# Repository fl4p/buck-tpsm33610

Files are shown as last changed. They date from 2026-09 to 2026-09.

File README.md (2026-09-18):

# buck-tpsm33610

A 3–36 V to 3.3 V, 1 A break-out board for the TI **TPSM33610S3QRDNRQ1** — a
synchronous buck *module* with the controller, both FETs, the inductor and the
bootstrap capacitor inside one 3.5 × 4.5 × 2.1 mm QFN-FCMOD package.

**9.01 × 12.525 mm**, 2 layers, one 2.54 mm header row: VIN, GND, VOUT.

> **Status: unbuilt.** This board has never been fabricated, assembled or
> powered. No gerbers have been generated. Every number below is either a
> datasheet value or a computed estimate — none of it is a bench measurement.
> Treat it as a design under review, not a validated product.

## What is generated

Everything. The KiCad symbol, footprints, schematic and PCB are all outputs of
the Python in this repo; the `.kicad_sch` and `.kicad_pcb` are build artefacts
and hand edits in the GUI are overwritten on the next run.

```
variants.py           geometry constants -- the single source of truth
project_settings.py   owns .kicad_pro design rules; apply() / verify()
gen_sym.py         -> lib/buck-tpsm33610.kicad_sym
gen_fp.py          -> lib/buck-tpsm33610.pretty/*.kicad_mod
gen_sch.py         -> buck-tpsm33610.kicad_sch
gen_pcb.py         -> buck-tpsm33610.kicad_pcb   (placement, routing, pours, fill)
check_netlist.py      capture-completion gate
```

Regenerate, in order. `gen_pcb.py` needs KiCad's bundled interpreter, the only
one that can `import pcbnew`:

```sh
KI=/Applications/KiCad/KiCad.app/Contents
KIPY=$KI/Frameworks/Python.framework/Versions/Current/bin/python3
CLI=$KI/MacOS/kicad-cli

python3 gen_sym.py && python3 gen_fp.py && python3 gen_sch.py
$CLI sch erc --severity-all --exit-code-violations -o erc.rpt buck-tpsm33610.kicad_sch
$CLI sch export netlist -o buck-tpsm33610.net buck-tpsm33610.kicad_sch
$KIPY gen_pcb.py
$CLI pcb drc --severity-all --schematic-parity --exit-code-violations \
     -o drc.rpt buck-tpsm33610.kicad_pcb
```

Built and verified against KiCad 10.0.5.

Two flags matter more than they look. `--exit-code-violations` is not
decoration: without it `kicad-cli` writes the violations to the report and still
exits 0. And DRC is deliberately run **without** `--refill-zones` — re-pouring
from the project at check time grades a board that is not the one in the file,
and that is exactly how an isolated pad hid here once.

## Design

| | |
|---|---|
| Input | 3–36 V (40 V abs max), no reverse-polarity or transient protection |
| Output | 3.3 V fixed, 1 A, ±1 % |
| Switching | 2.2 MHz, auto/PFM by default (see DRSS note below) |
| Layers | 2 × 35 µm (1 oz), ENIG, 1.6 mm FR4 |
| Drawn to | 150 µm track / 150 µm clearance |
| I/O | one 1×3 header, 2.54 mm: VIN, GND, VOUT |
| Control | EN, PGOOD, MODE on 1.0 mm solder pads; JP1 selects FPWM |

Pin rules from TI **SNVSCS7E** that shape the whole layout: SW (5, 6) carries no
copper beyond its lands; BOOT (7) is a no-connect because the 100 nF is internal;
MODE/SYNC (11) has a **5.5 V abs max** and must never reach VIN; PGOOD (1) tops
out at 20 V, so its pull-up goes to VOUT. `gen_sch.py` asserts these as an
abs-max-per-pin gate at generation time, so a net that could over-volt a pin
fails the build rather than the board.

The datasheet states the 100 nF bootstrap cap is internal (p.5, pin 7) and
requires external bypass at VIN (p.5, pin 3). It does not say whether any
internal VIN bypass exists; assume none and bypass externally.

### Two layers

TI's datasheet asks for four. The cost is quantified rather than waived: on a
1.6 mm two-layer board the image plane sits 1.6 mm below F.Cu instead of ~0.2 mm,
so a top-side switching run encloses roughly 8× the area. What makes it
defensible is that the highest-di/dt loop is kept small locally and the back side
is one unbroken ground pour.

### Verification gates

The generators are gates, not reports — each fails the build:

- **Fill runs in a clean subprocess.** `CreateEmptyBoard()` loads KiCad's default
  project into the interpreter, and a later `LoadBoard()` in the same process
  keeps those defaults, so an in-process pour uses the wrong clearances. This
  cost a silently isolated pad once.
- **Connectivity after fill** — every pad must reach every other pad on its net,
  or the build fails.
- **Courtyard overlap by polygon intersection**, not inflated bounding boxes.
- **Abs-max per U1 pin** from the datasheet table.
- **BOM line consistency** — parts sharing an MPN must agree on value and footprint.
- **MODE never floats** in any jumper state.

## Known and open

- **Thermal is an estimate, not a measurement, and the estimate is unsourced.**
  ~120 °C/W at the 35 µm this board actually specifies, against TI's 54.1 °C/W
  JESD 51-7 four-layer figure and 22 °C/W for their EVM. No derivation for that
  number exists in this repo — treat it as an order-of-magnitude expectation, not
  a bounded estimate. That predicts full 1 A to roughly 80 °C ambient at
  24 V and ~64 °C at 36 V. Unverified. ΨJB is 16.3 °C/W, so the acceptance test
  is to probe board temperature beside the GND land and compute
  `Tj = Tboard + 16.3 × Pd`.
- **Input loop inductance: 3.67 nH of board copper** (C1‖C2), extracted with
  FastHenry at 0.25 mm mesh pitch, ±1 % over a 2.5× pitch range. This is **board
  copper only and a lower bound** — the module's pad-to-die path is not published
  and is deliberately not estimated. Not cross-checked against hardware. **The
  extraction tool is not in this repo** and neither is its output, so nothing here
  substantiates that figure; it is reproduced from an external run.
- **The VIN neck is 0.245 mm and is marginal at the specified copper weight.**
  At 35 µm, IPC-2221 gives **0.86 A at 10 K rise and 1.17 A at 20 K**. Worst-case
  input current is ~1.0–1.1 A, which occurs at the low end of the *regulating*
  input range (around 3.5–4 V, where duty is highest); below that the part is in
  dropout and no longer making 3.3 V. So the neck sits **above its 10 K rating and
  inside its 20 K rating** — it works, at a higher local rise than is comfortable.
  At 70 µm the same neck gives 1.43 A / 1.93 A and is unambiguously fine. TI asks
  for 2 oz outer layers (SNVSCS7E p.35 item 6); this board is drawn at 1 oz.
- **Resistance of the declared power paths** at 35 µm, 0.1 mm solver grid:
  `/VIN C1.1↔U1.3` 9.27 mΩ, `/VIN J1.1↔U1.3` 11.04, `GND J1.2↔U1.10` 3.23,
  `GND C2.2↔U1.10` 2.36, `/VOUT J1.3↔U1.4` 1.84, `/VOUT U1.4↔C4.1` 0.96.
- **Spread spectrum is mostly OFF in the shipped default.** Table 7-2 calls the
  MODE-low state "auto mode with spread spectrum", but §7.3.8 p.18 overrides it:
  DRSS is disabled whenever the clock is not free-running — including when the
  clock slows under light load in auto mode, and in dropout. Bridge JP1 for FPWM
  if you want DRSS active at light load.
- **Two accepted DRC warnings**: the C1–C4 courtyard overlap (side-by-side pair
  whose cheapest escape is X, not Y) and an R3/R6 silkscreen clearance. Zero
  errors, zero unconnected pads. The generators cite a `DESIGN.md` for the
  per-pair disposition of those warnings; **that file does not exist**, so the
  waiver is currently undocumented.
- **No input protection at all** — no TVS, no reverse-polarity FET, not even a
  DNP land. EN is hard-tied to VIN. Nothing here survives a hot-unplug inductive
  kick on a long 36 V lead. Bench use from a stiff supply only.
- `make_fab.py` is not written, so there are no gerbers and no assembly data.

## Datasheet

TI **SNVSCS7E**, "TPSM336xx-Q1". Not redistributed here —
`datasheets/PROVENANCE.md` carries the source URL and the SHA-256 of the exact
revision every page citation in this repo refers to.

## History

Developed inside a private monorepo; this repository starts from a squashed
snapshot, so the per-change history is not carried over.

## Licence

Not yet chosen, so no licence is granted — all rights reserved for now. If you
want to use any of this, open an issue and ask.

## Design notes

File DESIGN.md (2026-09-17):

# buck-tpsm33610 — design record

This file exists because four generators defer to it: `gen_sch.py` for design
intent and the capture record, `gen_pcb.py` and `project_settings.py` for the
courtyard-warning disposition, and `gen_fp.py` for the copper-weight claim. It
was missing until 2026-09-17 — an independent review found that the DRC waivers
were made **by reference to a document that did not exist**. Every disposition
below is either evidence or is labelled as a preference.

Status of the board: **unbuilt**. Nothing here is a bench measurement.

---

## 1. Intent

TI's Table 8-3 fixed-output application — CIN bulk + 100 nF HF, CVCC, one COUT,
FB tied to VOUT — plus exactly three additions:

1. **R1, a 0 Ω RFBT that doubles as the fixed/adjustable selector.** §7.3.2.1
   p.12: the part *"determines whether fixed output voltage or adjustable output
   voltage is required by sensing the resistance of the feedback path during
   start-up."* 0 Ω fitted = fixed. Retune R1 and fit R2 to go adjustable.
2. **R4/R5, an EN strap that can become a UVLO divider.** R4 = 0 Ω VIN→EN as
   built.
3. **R6 + JP1, the MODE strap.** R6 100 k to GND is auto/PFM. Bridge JP1 for
   FPWM via VCC.

Everything else is either the datasheet's required external or a DNP land.

## 2. Capture record — as-captured netlist

Exported from `buck-tpsm33610.kicad_sch`, this is the artefact `--schematic-parity`
checks the PCB against:

```
/EN      R4.2 R5.1 TP1.1 U1.2
/FB      C6.2 R1.2 R2.1 U1.9
/MODE    JP1.2 R6.1 TP3.1 U1.11
/PGOOD   R3.2 TP2.1 U1.1
/SW      U1.5 U1.6
/VCC     C3.1 JP1.1 R3.1 U1.8
/VIN     C1.1 C2.1 J1.1 R4.1 U1.3
/VOUT    C4.1 C6.1 J1.3 R1.1 U1.4
GND      C1.2 C2.2 C3.2 C4.2 J1.2 R2.2 R5.2 R6.2 U1.10
unconnected-(U1-BOOT-Pad7) U1.7
```

`/SW` is a legitimate two-node net — pins 5 and 6 are the same internal node, and
a minimum-length inter-land stub satisfies ERC without inventing SW copper.
BOOT is explicitly no-connected; its capacitor is internal.

### Deviations from the original plan, and why

| plan | as built | why |
|---|---|---|
| J1 + J2, two 1×4 rows on 0.400 in, breadboard straddle | **one 1×3 header**, VIN GND VOUT | the board shrank to 9.01 mm wide, which cannot span 10.16 mm rows. The straddle was given up when the board was made small. |
| C7, second 22 µF COUT (DNP) | not placed | no room after the shrink |
| R7, MODE pull-up (DNP) | replaced by **JP1** | a solder jumper selects FPWM without a second fit option, and removes the R6/R7 mutual-exclusion hazard entirely |
| TP1–TP5 | TP1–TP3 (EN, PGOOD, MODE) | VOUT_SENSE and GND test pads dropped for space |
| 200 µm track / 200 µm clearance | **150/150** | see §5 |
| 70 µm copper | **35 µm** | see §5 |

## 3. DRC dispositions

DRC is run **without** `--refill-zones` — re-pouring from the project at check
time grades a board that is not the one in the file, and gerbers come from the
file. Current result: **0 errors, 0 unconnected pads, 2 warnings**, both below.

### `courtyards_overlap` — C1 / C4 — ACCEPTED

`project_settings.py` demotes this rule to *warning* rather than `ignore`, so it
still appears in every report and cannot pass unnoticed.

C1 (CIN bulk, 1206) and C4 (COUT, 1206) sit side by side in the southern power
row. Their courtyards are each the part's real body plus the standard IPC 0.25 mm,
and they overlap in X. **The copper does not.** The measured pad-to-pad copper gap
between the two parts clears `clearance_mm`, and `kicad_copper_collisions.py`
reports 0 collisions on the built board.

Why it is not fixed rather than waived: two overlapping courtyards share a Y range
by definition, so no cut line separates them — growing the board cannot reach this
pair, and their cheapest escape is X, which is the axis already at its limit.
Shrinking a courtyard to silence the warning would be a mute button: it would
change the reported number without changing the geometry.

**Accepted risk:** courtyard is a placement/assembly convention, not a fab rule.
Two 1206s at this spacing are within reflow practice. If this board is ever
hand-reworked with hot air, C1 and C4 will heat together.

### `silk_overlap` — R3 / R6 — ACCEPTED

0.070 mm between silkscreen segments against a 0.100 mm rule. R3 and R6 are two
of the five west-face rows, moved 0.25 mm south on 2026-09-16 to clear a
*courtyard* overlap; their reference designator outlines now touch.

This is ink on ink, not copper, and it is silkscreen-to-silkscreen rather than
silk-to-pad — no pad is obscured. The cost of fixing it is re-opening the west
cluster spacing that was just tightened to fix a real courtyard overlap.

**Accepted risk:** cosmetic. Two designators may bleed together on the printed
board.

## 4. MODE / JP1 — a hazard that is not a DRC finding

**Bridging JP1 while also driving TP3 shorts an external driver to VCC.**

JP1 open: MODE is held at GND through R6 100 k — auto/PFM. A clock or logic level
on TP3 overrides it, which is why R6 is 100 k and not 0 Ω.
JP1 bridged: MODE is tied to VCC — FPWM. **TP3 must then be left alone.** Driving
TP3 low against a bridged JP1 puts the external driver across the internal LDO.

This is stated in JP1's `Spec` field in the schematic as well as here.

MODE's absolute maximum is **5.5 V** (SNVSCS7E p.6) and VCC is 3.1–3.5 V, so the
bridged state is legal. MODE must never see VIN. `check_net_ceilings()` proves
that from the netlist rather than from a comment.

## 5. Process — 35 µm ENIG, and why the copper weight is not free

Confirmed by Fab 2026-09-16: **35 µm (1 oz) ENIG**.

TI asks for 2 oz outer layers and no less than 1 oz (p.35 item 6). This board is
at that floor, and the reason is the land, not the thermals:

- The RDN0011B land has a **0.100 mm minimum copper gap** (pins 1–11 and 8–9),
  which is finer than every published Aisler 2-layer rule. It is a deliberate,
  scoped rule break — decided 2026-09-13, Fab: *"the aisler rules are
  conservative, breaking the rules has always worked so far, no bad boards."*
- At **35 µm** that gap is 1.25× under the 125 µm ENIG rule, with an etch aspect
  ratio around 0.35:1 — the rule is margin, not physics.
- At **70 µm** it is 1.75× under *and* about 0.7:1 in aspect ratio, which is a
  physical limit. This is the one place on the board where the rule should not be
  broken.

Independently, the board is drawn to **150/150 µm** outside the land (35 copper
tracks sit on that floor). That clears Aisler's 125/125 ENIG rule but **not**
35 µm HASL's 200 µm track rule. So the process is pinned: **ENIG, 35 µm**, and
the copper weight is not a choice deferred to checkout.

### What 35 µm costs

- **Thermal.** The 70 µm option was worth roughly **10 °C of ambient headroom**.
  That figure and the ~105 → ~120 °C/W θJA behind it are **estimates with no
  derivation in this repo** — an order-of-magnitude expectation, not a bounded
  result. TI publishes 54.1 °C/W (JESD 51-7, four layers, 76.2 × 114.3 mm) and
  22 °C/W (four-layer EVM); this board is two layers and ~113 mm².
  **Acceptance test:** ΨJB is 16.3 °C/W (p.7), so probe board temperature beside
  the GND land and compute `Tj = Tboard + 16.3 × Pd`. Until that is done the
  thermal claim stays an estimate.
- **The VIN neck.** 0.245 mm at 35 µm gives IPC-2221 **0.86 A at 10 K rise,
  1.17 A at 20 K**. Worst-case input current is ~1.0–1.1 A, at the low end of the
  *regulating* input range (~3.5–4 V, where duty is highest); below that the part
  is in dropout and is not making 3.3 V. So the neck runs **above its 10 K rating
  and inside its 20 K rating**. Accepted: it works, warmer than is comfortable.

### Measured path resistances

35 µm, 0.1 mm solver grid, `copper_guards.py resistance`:

| path | mΩ | budget |
|---|---|---|
| /VIN C1.1↔U1.3 | 9.27 | 5 — see below |
| /VIN J1.1↔U1.3 | 11.04 | 25 |
| GND J1.2↔U1.10 | 3.23 | 10 |
| GND C2.2↔U1.10 | 2.36 | 5 |
| /VOUT J1.3↔U1.4 | 1.84 | 10 |
| /VOUT U1.4↔C4.1 | 0.96 | 3 |

**The 5 mΩ on `/VIN C1.1↔U1.3` is not a derived limit.** It was written into the
plan without a failure mode behind it, and it is recorded here as a preference so
that nobody — including a future me — cites it as a spec. The same applies to the
plan's `L_in(HF) ≤ 3 nH`. The input-loop criterion that *is* derived is the
**8 nH total**, from overshoot against the 40 V abs max (p.6): at ~0.33 A/ns,
8 nH gives 2.6 V and 36 + 2.6 = 38.6 V. FastHenry measures **3.67 nH of board
copper** for C1‖C2 — board copper only and a lower bound, since the module's
pad-to-die path is not published.

Note the solver's default `--grid 0.2` makes the GND solve **exactly singular**
(nan) on this board; the guard fails closed on it. Use `--grid 0.1`.

## 6. Known gaps

- **No gerbers.** `make_fab.py` is not written.
- **No staleness gate** between `gen_sch.py` → `.net` → `gen_pcb.py`. Nothing
  checks that the netlist was exported from the current schematic; run the chain
  in order. This bit during the 2026-09-17 session — a `gen_pcb.py` run consumed
  a netlist from the previous day.
- **`gen_fp.py` does not prune** stale `.kicad_mod` files. Four are generated and
  four are present, so nothing is stale today, but a footprint rename leaves the
  old file behind and the board can silently keep using it.
- **Two claims unverified** by the 2026-09-17 review: exact pad X/Y against the
  p.47 land drawing, and the measured `/SW` copper area.

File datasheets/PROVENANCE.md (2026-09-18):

# Datasheet provenance

Where each PDF in this directory came from, so a claim sourced from one can be
re-checked without guessing which document or revision was read.

| file | part | document | retrieved | source URL |
|---|---|---|---|---|
| `TI-TPSM336xx-Q1-SNVSCS7E-revE.pdf` | TI **TPSM33610S3QRDNRQ1** (U1) | **SNVSCS7E**, APRIL 2025 – REVISED SEPTEMBER 2026 (Rev. E) | 2026-09-13 | `https://www.ti.com/lit/ds/symlink/tpsm33610-q1.pdf` |

SHA-256:

```
59703a765616bffb3e0278fa0100bafd4b9f95aa9751f244311d5f2f2782d572  TI-TPSM336xx-Q1-SNVSCS7E-revE.pdf
```

Hashed **after** the copy into this directory, not at download.

**The PDF itself is not stored in this repository.** TI's document is not
redistributed here; fetch it from the source URL above and check it against the
SHA-256 before reading a number out of it. `datasheets/*.pdf` is gitignored.

## Fetch record

Rung 1 of the access ladder (plain `curl -L` with a desktop Chrome UA) returned
the document on the second URL tried. Recorded because the first URL is the one
an obvious guess produces and it is wrong:

| URL | result |
|---|---|
| `https://www.ti.com/lit/ds/symlink/tpsm33610.pdf` | **HTTP 404**, 3298 bytes of HTML — TI's "Error 404 not found" page, saved under a `.pdf` name. Not a datasheet. |
| `https://www.ti.com/lit/ds/symlink/tpsm33610-q1.pdf` | HTTP 200, 3 231 249 bytes, `%PDF-1.6`, 49 pages. **This file.** |
| `https://www.ti.com/lit/gpn/tpsm33610-q1` | HTTP 200, byte-identical to the above |

No WAF, no interstitial, no CAPTCHA. Judged by content: `pdfinfo` reports
`Keywords: SNVSCS7E`, `Author: Texas Instruments, Incorporated [SNVSCS7,E?]`,
`Title: TPSM336xx-Q1 Automotive, 3V to 36V Input, 1V to 7V Output, 0.6A, 1A, and
2A Synchronous Buck Converter Power Modules in a HotRod™ QFN Package With
Mitigated Interference and Noise Technology (MINT) datasheet (Rev. E)`.

## Why the family document, and what it costs

There is no `TPSM33610S3QRDNRQ1`-only datasheet. SNVSCS7E covers three current
ratings — TPSM33606-Q1 (0.6 A), **TPSM33610-Q1 (1 A, ours)** and TPSM33620-Q1
(2 A) — in two fixed-output trims (3.3 V `S3`, 5 V `S5`) plus an adjustable part.
**Most of the application tables in Section 8 are written against the 2 A part.**
Anything read from this document must therefore name the device column, not just
the page. In particular:

- **Table 8-1 and Table 8-2 (p. 26) are `TPSM33620-Q1`.** They call for
  2 × 22 µF of COUT. They are *not* the component table for this board.
- **Table 8-3 (p. 26) is the fixed-output `TPSM33610/06-Q1` table** — the one that
  applies here: CIN 4.7 µF + 100 nF, CVCC 1 µF, **COUT 1 × 22 µF**, RFBT short,
  RFBB and CFF do-not-populate.
- The **Thermal Information table (p. 7) is shared across all three dies**, and the
  RθJA figure printed there is measured on `TPSM33625EVM` (22 °C/W) or a 4-layer
  JESD 51-7 board (54.1 °C/W). Its own footnote says the JESD value "can not be
  used for design purposes."
- The **current-limit rows in the Electrical Characteristics (p. 7–8) are
  per-device.** Ours is `IL_HS` 1.7/2.0/2.3 A, `IL_LS` 0.85/1.1/1.4 A — *not* the
  3.4/4/4.6 A row, which is the 2 A part.

## Page map used by this project

Cite these page numbers, not section numbers alone; they are PDF pages of this
exact file (49 pages total).

| topic | page |
|---|---|
| Device Comparison Table — `TPSM33610S3QRDNRQ1` = "3.3 V fixed / adjustable", spread spectrum **yes** | 4 |
| Figure 5-1 pinout, **TOP VIEW**, + Pin Functions table | 5 |
| Absolute Maximum Ratings — VIN 40 V, **MODE/SYNC 5.5 V**, EN 40 V, PG 20 V, VOUT 16 V, FB 16 V | 6 |
| Thermal Information (RθJA 22 / 54.1, ΨJB 16.3) + Electrical Characteristics | 7–8 |
| §7.3.2 Output Voltage Selection; Eq. 1–3; Table 7-1 divider values | 12–13 |
| §7.3.3 Enable, start-up, shutdown | 14–15 |
| §7.3.4 External CLK SYNC; Table 7-2 mode selection; pulse-dependent MODE control | 15–17 |
| Table 8-3 — **fixed-output TPSM33610/06-Q1 external components** | 26 |
| §8.2.2.3 input capacitor selection + recommended parts | 27–28 |
| Thermal design, IOUT,max equation (9) | 29 |
| Efficiency curves, 3.3 V / 2.2 MHz | 30 |
| §8.5.1 Layout Guidelines; Figure 8-19 fast-edge current loops | 34–35 |
| §8.5.2 Layout Example, Figures 8-20 / 8-21 | 36 |
| §9.1.3 Device nomenclature (decodes `S3` = 3.3 V fixed, `S` = spread spectrum on) | 37 |
| **PACKAGE OUTLINE RDN0011B**, drawing 4231197/B 08/2025 | **46** |
| **EXAMPLE BOARD LAYOUT / LAND PATTERN EXAMPLE** | **47** |
| **EXAMPLE STENCIL DESIGN** | **48** |

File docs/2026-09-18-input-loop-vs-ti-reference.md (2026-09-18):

# The input loop measured, and how it compares with TI's own reference

**2026-09-18. Analysis only — nothing in this document was measured on hardware.** The
board has been sent to fab at revision `e6fe53a`; see §4.4, which is the section to read
if you only want to know what the hardware in flight can do. It records what the extracted copper and the vendors' own
capacitor data say about the input bank, what TI's datasheet and EVM do differently,
and which of those differences are worth acting on.

Tooling and provenance: `pv/ee/dcdc-tools/mlcc/` (commits `d396b52` … `806b2b0`),
which reads vendor curves and SPICE models from `vendorpull/store` and the board
copper from `pv/ee/dcdc-tools/parasitics` (FastHenry). Three independent Codex reviews
of that code raised twenty findings, all real, all fixed; the numbers below are
post-review. Everything here ran against a **scratch copy** of this project — the
board files were never written, and the KiCad locks were left alone.

To reproduce the tables: `python3 -m mlcc.vin_budget_tpsm33610` from `dcdc-tools`. It
reads an extraction JSON, so pointing it at a different board means re-running the
parasitics extractor first — and at the commit that was fabricated (§4.4), not at HEAD.

---

## 1. The limit, and where it comes from

TI publishes no input-ripple spec. It publishes a rating, and a warning:

* SNVSCS7E rev E §6.1 — **VIN to GND absolute maximum 40 V**; §6.3 recommends 3–36 V.
* §7.3.1 — *"Take extra care to confirm that the voltage at the VIN pin does not exceed
  the absolute maximum voltage rating of 40 V during line or load transient events.
  Voltage ringing at the VIN pins that exceeds the absolute maximum ratings can damage
  the IC."*

So at the top of the input range the **entire** ripple-plus-ring budget at the pin is
**4.0 V**, and only there: at 24 V in there is 16 V of headroom. The EN pin, tied to VIN
through R4, carries the same 40 V rating, so it is not a tighter constraint.

The 5 mΩ input-impedance target quoted in earlier discussion was never derived from
anything. This one is.

## 2. Two failure modes, with different causes and different fixes

**(a) The switching edge.** The pin sees `L_trunk × Iout / t_edge` — the shared copper
between the module pins and the point where the capacitors meet. TI publishes no edge
rate, so this is a parameter sweep, never a prediction. At 36 V, 1 A, board copper only,
the excursion **above** the rail (the one the rating has to survive):

| t_edge | overshoot | VIN peak | headroom |
|---|---|---|---|
| 1 ns | 3.93 V | 39.93 V | **0.07 V** |
| 2 ns | 1.90 V | 37.90 V | 2.10 V |
| 5 ns | 0.68 V | 36.68 V | 3.32 V |
| 20 ns | 0.13 V | 36.13 V | 3.87 V |

**(b) The C1/C2 anti-resonance.** The two branches are 4.633 nH (C1) and 0.646 nH (C2) —
a 7× imbalance — which resonates at 5.8 MHz at 36 V with a peak near 1.3 Ω. Worst single
harmonic across VIN and the switching-frequency band: **436 mV pp** (vendor-curve basis)
/ 417 mV (vendor-model basis), the third harmonic at 36 V. That figure is *optimistic*:
the model takes ESR from the 0 V curve at a bias-shifted resonance, which overstates
damping (see §6).

Note the switching frequency is a band, not 2.2 MHz: `tON_MIN` is 65 ns typ / 75 ns max
(§6.5), so above ~20 V the module stretches its cycle (§7.4.3.4), and the clock itself is
2.1/2.2/2.3 MHz with ±4 % DRSS, which this device option enables.

## 3. What the copper can and cannot fix

Measured on a scratch copy: the project was copied out, regenerated with its own
`gen_pcb.py` under KiCad's python, and re-extracted. The unmodified copy reproduces the
committed extraction exactly (L_loop 3.6710 nH, trunk 3.1038, C2 0.6464, C1 4.6331), so
the deltas below are the variants and not the pipeline. Both variants regenerate with no
new DRC severities.

| variant | trunk | L_loop | loop R | overshoot @1 ns | worst harmonic |
|---|---|---|---|---|---|
| as built | 3.104 nH | 3.671 nH | 7.96 mΩ | 3.93 V | 436 mV |
| VIN stub 0.30/0.40 → 0.55 mm | 2.974 | 3.542 | 7.05 | 3.80 V | 429 mV |
| + a third GND via on the hot return | 2.999 | 3.493 | 6.78 | 3.75 V | 440 mV |
| + C1 branch at 1.0 nH *(assumed, not extracted)* | 2.999 | — | — | 3.65 V | **123 mV** |

**Routing tweaks do not buy the VIN margin** — 5 % off L_loop moves the headroom 0.07 →
0.25 V. The placement was already close to its floor before this analysis existed: C2 is
hard against the pin row (swapped with R4, citing §8.5.1 item 1), the hot return already
has two parallel vias plus one at U1.10, and C1 is rotated so its VIN pad faces the
module. What widening copper *does* buy is resistance (−15 %), which is damping.

**Moving C1 next to C2 is worth 72 % of the resonance** and almost nothing on the edge.
It is a placement-and-routing change (C1's VIN feed would have to cross C2's ground pad),
and the 1.0 nH is an assumed branch — the prize, not a measurement of a real layout.

## 4. TI's reference design, and the three things it does differently

From §8.5.2 Figure 8-21 and the TPSM33620QEVM user's guide (SNVU943 §4.3):

| | TI | this board |
|---|---|---|
| stackup | 4 layers, ground plane under the top, 2 oz outer / 1 oz inner | 2 layers, 35 µm, return 1.6 mm away |
| HF cap | ~100 nF 0402/0603 **on the bottom**, "through via nearest to VIN pin" | none on the bottom |
| input bank | 2 × 4.7 µF 1210 + 0.1 µF 0402 + **100 µF aluminium** | 10 µF 1206 + 1 µF 0603, no bulk |

### 4.1 The stackup is the biggest lever

Measured by moving the return pour closer to the top copper. The extractor spaces copper
layers evenly through the board thickness and via barrels shorten with it, so this is a
faithful **proxy** for a ground plane on layer 2 — not a drawn 4-layer board:

| return plane | trunk | L_loop | overshoot @1 ns | VIN peak | worst harmonic |
|---|---|---|---|---|---|
| 1.6 mm (as built) | 3.104 nH | 3.671 nH | 3.93 V | 39.93 V | 436 mV |
| 0.8 mm | 2.166 | 2.511 | 2.70 V | 38.70 V | 357 mV |
| 0.4 mm | 1.633 | 1.921 | 2.20 V | 38.20 V | 294 mV |
| 0.2 mm | 1.256 | 1.514 | **1.82 V** | 37.82 V | **226 mV** |

A plane at 0.2 mm takes 60 % off the trunk where routing took 3 %, and it is the only
change found that improves **both** failure modes at once. It is also a different
product: the 2-layer 35 µm ENIG choice is deliberate and documented in §5 of DESIGN.md
along with the rule-bending it required, and 4 layers with 2 oz outers changes fab, cost
and every clearance budget. The 2 oz copper itself mostly buys resistance, not
inductance.

### 4.2 The backside 100 nF — untested, and the cheapest item on the list

A capacitor under the pins on B.Cu is a third branch with an almost-zero shared path,
aimed straight at the edge term. It needs a schematic entry, a footprint on the back and
its vias, so it was not built in the scratch copy. **This is the recommended next
measurement** if the 40 V margin matters.

### 4.3 The bulk capacitor answers the capacitance question

TI's EVM ceramics alone: 9.50 µF nameplate, **3.87 µF effective at 36 V — 0.82×** of the
4.7 µF minimum. TI's own board does not meet an *effective* reading on ceramics either;
it meets it with the 100 µF electrolytic, which barely derates.

| bank | nameplate | effective @36 V | vs 4.7 µF |
|---|---|---|---|
| this board (10 µF + 1 µF) | 11.0 µF | 2.10 µF | 0.45× |
| TI Table 8-5 pair (4.7 + 0.1) | 4.8 µF | 1.95 µF | 0.41× |
| TI EVM ceramics (2 × 4.7 + 0.1) | 9.5 µF | 3.87 µF | 0.82× |
| this board + a second 10 µF 1206 | 21.0 µF | 4.08 µF | 0.87× |

Per part at 36 V, from the vendors' own DC-bias curves: TI's 4.7 µF 1210
(C3225X7R1H475K250AB) 4.435 → 1.924 µF (−57 %); the 0.1 µF 0402 (GRM155R61H104ME14D)
91 → 22 nF (−76 %).

**If the requirement is effective, the answer is bulk, not a bigger MLCC** — no
reasonable ceramic addition reaches 4.7 µF at 36 V.

Whether it *is* effective is unresolved: §8.2's note says application values are
effective unless stated otherwise and §8.2.2.3 does not state otherwise, but Table 8-5
footnote 2 marks TI's own recommendation as nameplate, and both TI's reference pair and
its EVM ceramics fail the effective reading. A public search (TI E2E, 2026-09-17) found
the same boilerplate across TI's module family and no answer for this part. **It needs a
question to TI.**

Also worth recording: on this board's copper, TI's Table 8-5 pair would be **worse** than
the parts fitted — 931 mV worst harmonic against 436, and a 4.34 Ω peak at 13.3 MHz
against 1.36 Ω at 5.8 MHz — because a 0.1 µF on the short branch rings harder against the
long one than the fitted 1 µF does. No part change is indicated. (Caveat: the copper was
extracted for 1206/0603 pads, not TI's 1210/0402.)

### 4.4 The board that went to fab is NOT the board in the repo

Checked 2026-09-18 after Fab reported the fabbed board has C1's GND pad on the right.
That is the orientation at **`e6fe53a`**; `92baceb` (2026-09-16) rotated C1 180 deg and
swapped C2/R4 so the input cap sits hard against the pin row. Everything in sections 2-3
above was extracted from repo HEAD, i.e. from a board that was never fabricated.

Extracted from `e6fe53a` itself, the same way:

| | trunk | L_loop | C2 branch | C1 branch |
|---|---|---|---|---|
| repo HEAD (C1 rot 180, C2 close) | 3.104 nH | 3.671 nH | 0.646 nH | 4.633 nH |
| **as fabbed (e6fe53a)** | **3.288 nH** | **3.890 nH** | 0.707 nH | 4.041 nH |

The fabbed board's shared trunk is 6 % LONGER — R4, not C2, had the slot against the pin
row — so its edge spike is 6 % larger. Its C1 branch is shorter, so the branch imbalance
is 5.7x rather than 7.2x and the resonance is slightly milder. The two changes pull in
opposite directions: **ripple a little better, VIN margin a little worse.**

### What the fabbed board does, 1 A out

| VIN | C_eff | worst harmonic | overshoot @1 ns | headroom | @2 ns | headroom |
|---|---|---|---|---|---|---|
| 12 V | 6.68 µF | 180 mV | 4.25 V | 23.8 V | 2.11 V | 25.9 V |
| 24 V | 3.53 µF | 351 mV | 4.15 V | 11.9 V | 2.01 V | 14.0 V |
| 30 V | 2.72 µF | 351 mV | 4.19 V | 5.8 V | 2.06 V | 7.9 V |
| 35 V | 2.15 µF | 383 mV | 4.14 V | **0.86 V** | 2.01 V | 3.0 V |
| 36 V | 2.10 µF | 390 mV | 4.12 V | **-0.12 V** | 1.99 V | 2.0 V |

**12-35 V at 1 A is fine.** The spike barely varies with input voltage (it is
`L·di/dt`, set by current and copper), so the headroom is simply `40 V - VIN - spike`.
36 V is the first point where the most pessimistic assumption (a 1 ns edge) crosses the
absolute maximum; 35 V keeps 0.86 V even there, and 3.0 V at a more typical 2 ns edge.
Input ripple stays under 0.4 V pp, about 1 % of the rail.

**So: run it at 12-35 V, 1 A. Do not sit at 36 V until the edge rate is measured.**

## 5. What to do

The hardware exists, so this splits into what governs *this* board and what governs the
next revision.

### 5.1 This board, now

1. **Run it at 12-35 V, 1 A** (§4.4). No change is required to do that.
2. **Measure the edge at bring-up before going above 35 V.** This is the single
   measurement that collapses the whole parameter sweep: the entire 36 V question is a
   disagreement between a 1 ns assumption (-0.12 V) and a 2 ns one (+2.0 V), and nothing
   in the analysis can settle it. See §5.3 for how.
3. **A backside 100 nF is retrofittable.** On a 2-layer board the bottom copper under the
   VIN pins is reachable; if the measured edge turns out to be fast, this is the fix that
   does not need a new board.

### 5.2 Next revision

1. **Decide the stackup question first.** It is the only change that fixes both modes,
   and it is a product decision (fab, cost), not a layout tweak.
2. **If staying 2-layer: add the backside 100 nF** as a placed part, and consider moving
   C1 beside C2. Take the copper tweaks (wider VIN stub, third via) as free damping.
3. **Add bulk** if the minimum-capacitance requirement turns out to be effective — and
   ask TI which it is (§4.3).
4. **Re-extract from the commit that is actually fabricated**, not from HEAD. §4.4 exists
   because that was not done.

### 5.3 The bring-up measurement

What to capture, so the result is comparable with the tables above:

* **Where:** across U1's VIN and GND *pads*, not at the connector and not across C1 —
  everything here is referenced to the module pads.
* **How:** ground spring, not a clip lead. A clip lead's own loop has been measured on
  this bench to invent ringing that is not there (`~/dev/kb`, sw-ring-15mhz-was-probe-clip).
* **What:** VIN at the switching edge, at 1 A, at 24 V and 35 V. Read (a) the peak
  excursion **above** VIN — that is the number §4.4 compares with 40 V — and (b) the
  10-90 % edge time.
* **The verdict:** the overshoot column of §4.4 is `L_trunk x Iout / t_edge`. If the
  measured edge is >=2 ns, 36 V has ~2 V of margin and the pessimistic row can be
  retired. If it is near 1 ns, 35 V is the ceiling as written.

## 6. What this analysis does not know

* **The module's internals.** The extraction closes the loop at the package pads. TI
  publishes no pad-to-die geometry and no internal decoupling, so every inductance here
  is a **lower bound**. TI's integration list names the FETs, controller, inductor and
  boot capacitor — no input capacitor.
* **The switch edge rate.** Unpublished; every number in §2(a) is conditional on it.
* **Damping near resonance.** ESR is read from the 0 V curve at a bias-shifted
  resonance. Against TDK's own encrypted DC-bias model at 36 V the construction reads
  8.6 mΩ (model basis) / 16.1 mΩ (curve) where TDK says 2.24 mΩ, i.e. too much damping,
  which **understates** resonant peaks. The 436 mV is therefore optimistic.
* **Temperature and tolerance.** Every curve used is 25 °C and one typical sample.
* **The vendors disagree with themselves.** A part's simple model and its own impedance
  curve differ on ESL by a median 1.79× across 1271 TDK parts, and the DC-bias models
  show the same gap. That is why every impedance figure here carries two bases; they are
  two vendor artifacts, not an error band. See
  `~/dev/kb/spice/mlcc-model-and-curve-disagree-on-esl.md`.

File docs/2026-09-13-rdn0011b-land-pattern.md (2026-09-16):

# RDN0011B land pattern, transcribed from SNVSCS7E

**Source.** TI SNVSCS7E rev E, `datasheets/TI-TPSM336xx-Q1-SNVSCS7E-revE.pdf`
(sha256 `59703a76…d572`), drawing **4231197/B 08/2025**:

| page | sheet |
|---|---|
| 46 | PACKAGE OUTLINE |
| **47** | **EXAMPLE BOARD LAYOUT / LAND PATTERN EXAMPLE** |
| 48 | EXAMPLE STENCIL DESIGN |

**Method.** Pages rendered with `pdftoppm -r 600 -png` and read as images in a
session carrying a `VISION-PROBE-PASS`. The drawing is vector, so the colours are
exact and separable: the pad outlines were extracted by colour
(`#6EDD00` green, `#007FFF` blue, `#FF0000` red) and measured in pixels, then
converted with a scale and origin fitted to the drawing's own ordinate callouts.
**Nothing below was reconstructed from the PDF text layer**, which lists the
callouts without their pairing and is exactly how a land pattern gets
transcribed wrong.

Calibration: 473.5 ± 1.0 px/mm at 600 dpi (drawing scale 20X). Origin = the
drawing's `0.000 SYMM ℄` (X) and `0.000 PKG ℄` (Y). Residual anisotropy between
the fitted X and Y scales was 0.25 %, i.e. ±0.005 mm over a pad — below the
rounding of every callout, but it is why the values below are taken from the
callouts wherever a callout exists, and from the measurement only where one
does not.

## Which colour is which — this inverts the usual convention

The SOLDER MASK DETAILS panel on p.47 carries two illustrations. Reading their
leaders:

- **green = SOLDER MASK OPENING**
- **blue dashed = METAL**

The main view draws blue **outside** green, which is the panel's right-hand case:
**SOLDER MASK DEFINED, and TI marks it `(PREFERRED)`**, `0.05 MIN ALL AROUND`.
This is the opposite of the TMP117 (SNOSD82D marks NSMD preferred) and the
opposite of Aisler's default +50 µm mask expansion. Measured directly on pin 1:
green 1.1213 mm wide, blue 1.2215 mm wide → **0.0501 mm per side**. Honour it
with a negative mask margin; do not let the fab's default invert it.

## Copper pads (F.Cu), top view, millimetres

Origin = package centre as defined by the drawing. +X right, +Y up, matching
Figure 5-1 (p.5) **TOP VIEW**, which is the orientation the land pattern is
drawn in (pin 1 upper-left in both).

| pin | name | centre X | centre Y | width | height |
|---:|---|---:|---:|---:|---:|
| 1 | PGOOD | −1.3875 | +1.960 | 1.225 | 0.470 |
| 2 | EN | −1.400 | +1.150 | 1.200 | 0.350 |
| 3 | VIN | −1.400 | +0.650 | 1.200 | 0.350 |
| 4 | VOUT | −1.200 | −0.995 | 1.600 | 2.150 |
| 5 | SW | +1.200 | −0.995 | 1.600 | 2.150 |
| 6 | SW | +1.400 | +0.650 | 1.200 | 0.350 |
| 7 | BOOT | +1.400 | +1.150 | 1.200 | 0.350 |
| 8 | VCC | +1.3875 | +1.960 | 1.225 | 0.470 |
| 9 | FB | +0.500 | +2.060 | 0.350 | 0.900 |
| 10 | GND | 0.000 | +1.690 | 0.400 | 1.620 |
| 11 | MODE/SYNC | −0.500 | +2.060 | 0.350 | 0.900 |

Corner radius `(R0.05) TYP` on every pad. Pin numbering and names are from
Figure 5-1 and the Pin Functions table, p.5.

### The callout that is easy to get wrong

`(1.3875)` and `(1.4)` are **two different ordinates**, not a rounding of one.
Pins 1, 2 and 3 share an **outer edge at X = −1.95** (`4X (1.95)`), but pin 1 is
1.125 wide where pins 2 and 3 are 1.100 wide (`2X (1.125)` vs `4X (1.1)`, both
mask-opening widths). So their centres differ:

```
pin 1   -1.95 + 1.125/2 = -1.3875      pins 2,3   -1.95 + 1.100/2 = -1.400
```

Mirrored for pins 8 and 6, 7. A transcription that collapses both to 1.4 puts
pins 1 and 8 0.0125 mm off; one that collapses both to 1.3875 puts four pads off.

## Solder mask openings (F.Mask)

For **pins 1, 2, 3, 6, 7, 8, 9, 10, 11**: the copper rectangle **inset 0.05 all
round**, i.e. `solder_mask_margin = -0.05`.

| pin | mask opening |
|---:|---|
| 1, 8 | 1.125 × 0.370 (`2X (1.125)`, `2X (0.37)`) |
| 2, 3, 6, 7 | 1.100 × 0.250 (`4X (1.1)`, `6X (0.25)`) |
| 9, 11 | 0.250 × 0.800 (`6X (0.25)`, `2X (0.8)`) |
| 10 | 0.300 × 1.520 (`(0.3)`, `(1.52)`) |

`6X (0.25)` covers six pads: 2, 3, 6, 7 (height) and 9, 11 (width).

**Pins 4 and 5 are different, and this is the whole point of the package.** The
copper is a plain 1.600 × 2.150 rectangle, but the mask opening is *not* that
rectangle inset — it is a lead-finger shape, because RDN is flip-chip-on-lead and
the package terminal only touches the board at the fingers. Measured profile of
pin 5 (mirror for pin 4):

```
body        X  +0.450 .. +1.575        Y  +0.030 .. -2.020     (1.125 x 2.050)
4 fingers   X  +1.575 .. +1.950        0.250 tall, 0.375 deep  ((0.375) TYP)
            finger centres Y = -0.30, -0.80, -1.30, -1.80      (2X (0.3), 6X (0.5))
            finger span 0.175 .. 1.925                          (2X (1.75))
            outer edge +1.950                                   (4X (1.95))
```

Measured finger centres: −0.2985, −0.7965, −1.2945, −1.7945 (pitch 0.498, 0.498,
0.500). `8X (0.25)` = four fingers on each of the two pads.

A KiCad pad carries one mask aperture concentric with its copper, so **pins 4 and
5 must not generate their own mask**: give the pad `F.Cu` only and draw the
finger outline as an `F.Mask` polygon in the footprint. Flattening it to a plain
1.5 × 2.05 opening would expose a 0.375 mm strip of copper along the outer edge
of each pad with no terminal above it to wet — a solder-beading invitation on the
two pads that carry all the current.

## Solder paste (F.Paste), from p.48

Stencil basis: **0.1 mm thick**, `PIN 4 & 5: 72% SOLDER COVERAGE BY AREA`.

- **Pins 1, 2, 3, 6, 7, 8, 9, 10, 11 — aperture = mask opening, 1:1.** Verified
  by measurement, not assumed: the red apertures measure within 1 px of the green
  openings (e.g. pin 1: 537 × 182 px red vs 536 × 182 px green; pin 10:
  147 × 726 vs 146 × 725).
- **Pins 4 and 5 — seven apertures each**, and KiCad cannot express that as one
  pad either, so these are `F.Paste` polygons alongside the mask polygons:

| aperture | count/pad | size | centre X (pin 5) | centre Y |
|---|---:|---|---:|---:|
| body upper | 1 | 0.930 × 0.510 | +0.910 | −0.230 |
| body middle | 1 | 0.930 × 0.620 | +0.910 | −1.000 |
| body lower | 1 | 0.930 × 0.510 | +0.910 | −1.770 |
| finger | 4 | 0.375 × 0.250 | +1.760 | −0.30, −0.80, −1.30, −1.80 |

Callouts: `6X (0.93)`, `4X (0.51)`, `2X (0.62)`, `3X (0.91)`, `8X (0.375)`,
`8X (0.25)`, `(1.76)`, `2X (0.23)`, `2X (1)`, `2X (1.77)`, `6X (0.5)`.

**Coverage check, and what it is a fraction of.** Per pad:

```
body      0.930 x (0.510 + 0.620 + 0.510)  = 1.5252 mm^2
fingers   4 x (0.375 x 0.250)              = 0.3750 mm^2
                                     total = 1.9002 mm^2

mask opening  1.125 x 2.050 + 4 x (0.375 x 0.250) = 2.68125 mm^2
coverage = 1.9002 / 2.68125 = 70.9 %   ->  TI's "72%" (they include the R0.05 corners)

against COPPER (1.600 x 2.150 = 3.44 mm^2) it would read 55.2 %
```

So TI's 72 % is referenced to the **mask opening**, not the copper. Any guard
that re-derives this number must divide by the same thing or it will "fail" a
correct stencil. The body apertures sit flush with the mask body's inner edge and
are inset 0.200 from its outer edge, which is what keeps body paste and finger
paste from merging.

## Recorded but deliberately not in the footprint

The p.47 view also shows TI's suggested **board** copper and vias, which Note 5
makes explicitly optional ("Vias are optional depending on application"). These
belong in `gen_pcb.py`, not the land:

- A **0.56 mm wide copper strip** (X = ±0.28) running from Y = +1.48 — where it
  meets the pin-10 land — down the centre to Y = −2.07, between the pin 4 and
  pin 5 lands. The 0.9 mm figure on the drawing is the *mask* gap between pins 4
  and 5, not this strip.
- **Ø0.2 vias** (`(0.2) TYP VIA`): three in the pin-10 land / centre strip at
  Y = 2.23, 1.23, 0.23; three in the pin 4 land and three in pin 5 at X = ∓1.73,
  Y = −0.55, −1.05, −1.55, with the mask opening notched around them (tented);
  and two open vias per big pad at X = ∓0.78, Y = −0.55 and −1.41.
- The pin-3 land carries two vias at X = −1.729 and −1.05, Y = +0.65.

## Verification: the generated footprint, overlaid on p.47

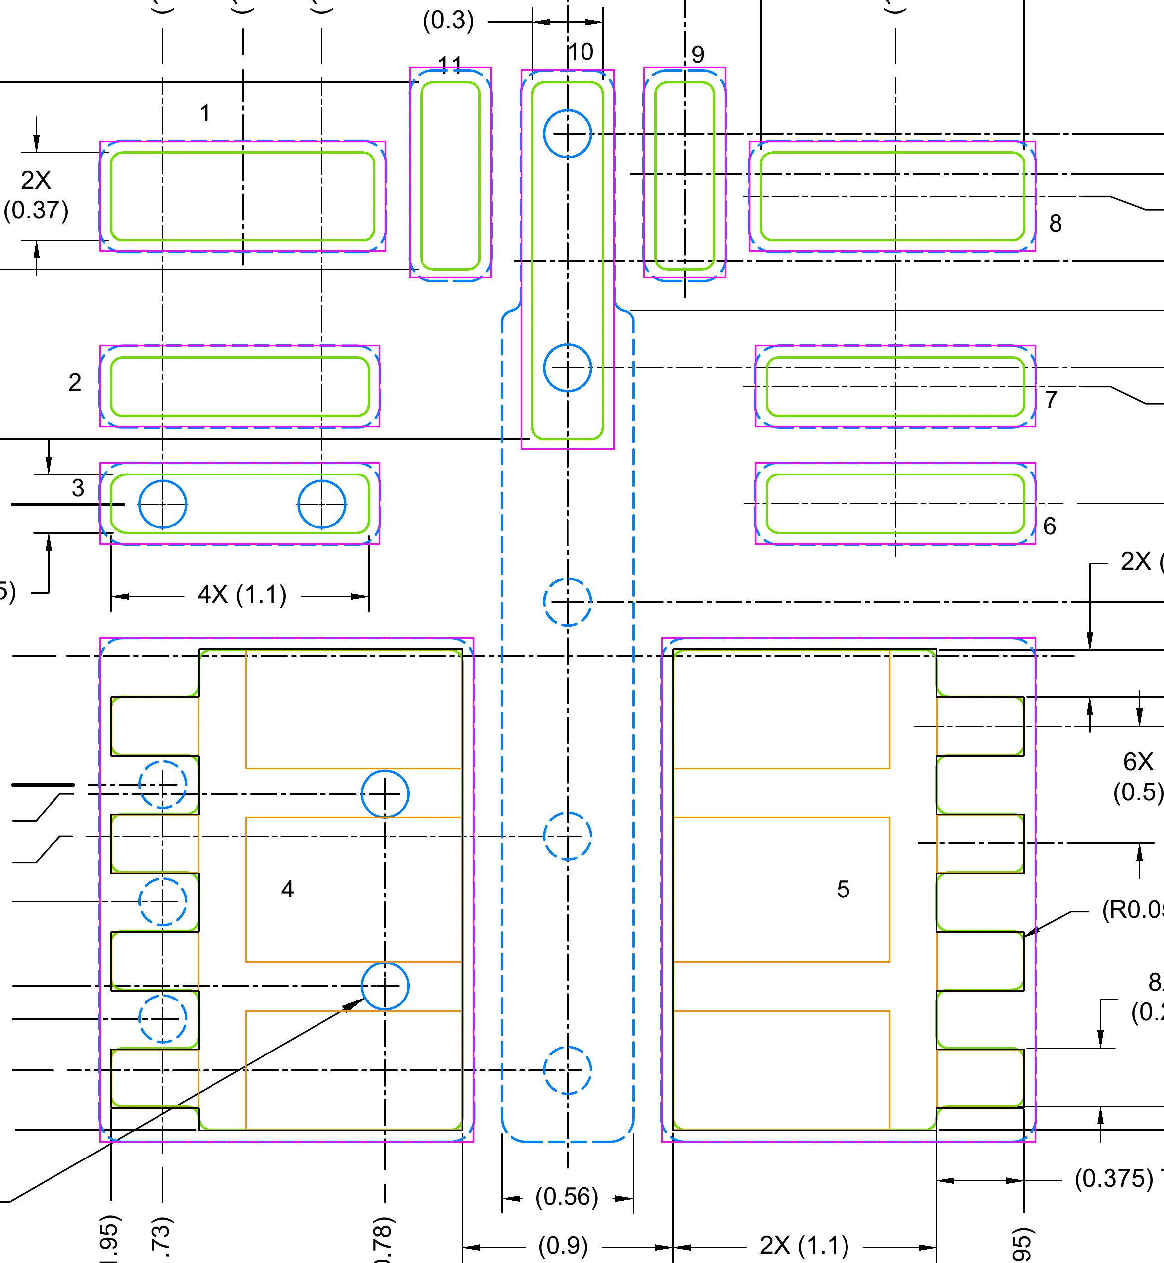
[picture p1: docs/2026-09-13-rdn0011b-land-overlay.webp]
land overlay


`lib/buck-tpsm33610.pretty/TPSM336xx_QFN-FCMOD-11_RDN0011B_TI.kicad_mod` was
re-parsed from disk (not from `gen_fp.py`'s intent), every pad converted back to
datasheet coordinates, and drawn onto the 600 dpi render of p.47 at the fitted
scale: **magenta = emitted copper, black = emitted F.Mask polygon, orange =
emitted F.Paste apertures.** Read visually in a `VISION-PROBE-PASS` session.

All eleven magenta rectangles sit on TI's blue metal outlines; the black polygon
traces the green lead-finger opening on both large pads, including all four
finger steps; the paste apertures sit inside the mask body. The wider pins 1 and
8 (1.225) versus pins 2, 3, 6, 7 (1.200) are visible and correct.

**Land pattern verified against SNVSCS7E p.47, drawing 4231197/B 08/2025.**

## Two rounding errors in TI's own stencil callouts

Guard 4 in `gen_fp.py` (paste must lie inside the mask opening) fired on the
literal p.48 numbers, twice. Both are the drawing rounding to two decimals:

| callout | taken literally | un-rounded | why |
|---|---|---|---|
| `3X (0.91)`, `6X (0.93)` | body aperture spans 0.445–1.375, i.e. 0.005 **outside** the mask body's 0.450 inner edge | centre **0.9125**, width **0.925** → 0.450–1.375 | flush inner edge, round 0.200 outer margin |
| `(1.76)` | finger aperture spans 1.5725–1.9475, 0.0025 outside the finger's 1.575 edge | centre **1.7625** | the aperture *is* the finger, 1.575–1.950 |

The same reasoning fixes `2X (0.23)`, `2X (1)`, `2X (1.77)` → centres −0.225,
−0.995, −1.765, which makes the top and bottom apertures flush with the mask
body and the two gaps between apertures equal at 0.205. The measured pixel
values (0.927 wide at X 0.913, centres −0.229/−0.996/−1.763) fit the un-rounded
numbers better than the printed ones, so this is un-rounding, not invention.

Recomputed coverage with the un-rounded values: **70.6 %** of the mask opening
(TI print 72 %; the remainder is their rounded corners, which this footprint
also has at R0.05).

## Manufacturability: this land is finer than the fab's rules

| gap | value |
|---|---|
| pins 1–11, 8–9 | **0.100 mm** |
| pins 9–10, 10–11 | 0.125 mm |
| pins 2–3, 6–7 | 0.150 mm |
| mask dam, everywhere | ≥0.200 mm (solder-mask-defined *widens* the dam) |

0.100 mm is under every published Aisler 2-layer rule (35 µm ENIG 125 µm, 35 µm
HASL 150 µm, 70 µm ENIG 175 µm, 70 µm HASL 225 µm) and under JLCPCB 2L (127 µm)
and PCBWay 2L standard (150 µm).

**Decision, Fab, 2026-09-13: build it untrimmed at 35 µm ENIG and accept the
rule break** — *"the aisler rules are conservative, breaking the rules has always
worked so far, no bad boards."* `gen_fp.py` prints the violation and its factor
(1.25×) on every run so it stays visible; `MIN_GAP` there is calibrated to the
package's 0.100 mm, not to the fab.

This is also why the copper stays **35 µm**. At 70 µm the same gap is 1.75×
under the rule *and* about 0.7:1 in etch aspect ratio — a physical limit rather
than a conservative one. The 70 µm option was worth roughly 10 °C of ambient
headroom; it is the one place on this board where the rule should not be broken.
The back-out, if a board ever returns with a short under the module, is the
documented `TRIM` table in `gen_fp.py`: 0.150 mm minimum gap at a cost of 15 %
of the wetted joint width on FB and MODE/SYNC.

## Unresolved

None. Every dimension callout on p.47 and p.48 is paired to a feature above, and
every pad edge is fixed by at least one named callout rather than by measurement
alone. The measurement and the callouts agree to ≤0.005 mm everywhere.

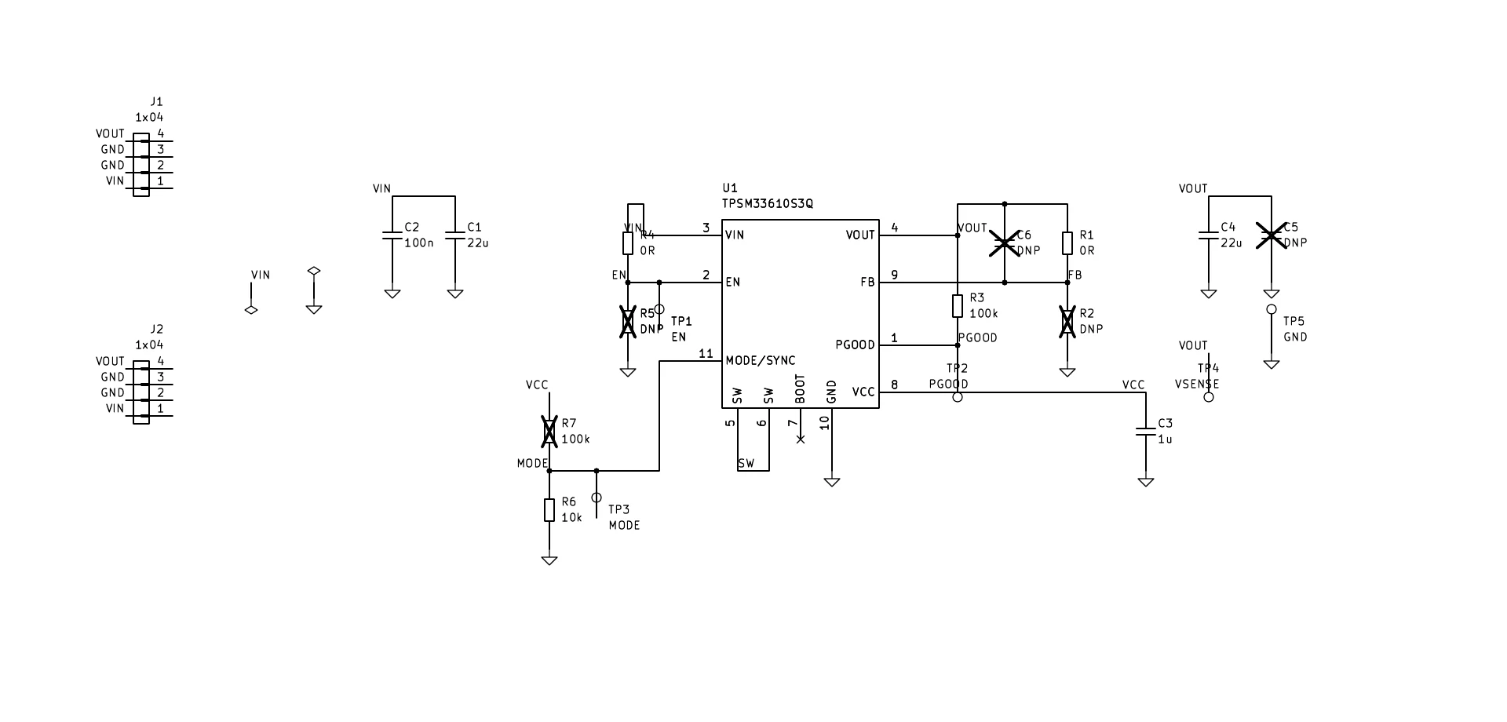
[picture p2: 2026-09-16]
docs/2026-09-13-schematic.webp

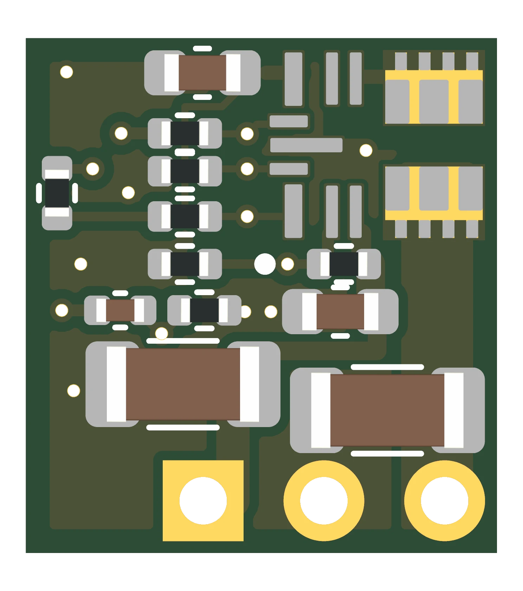
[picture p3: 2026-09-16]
docs/2026-09-13-routed-top.webp

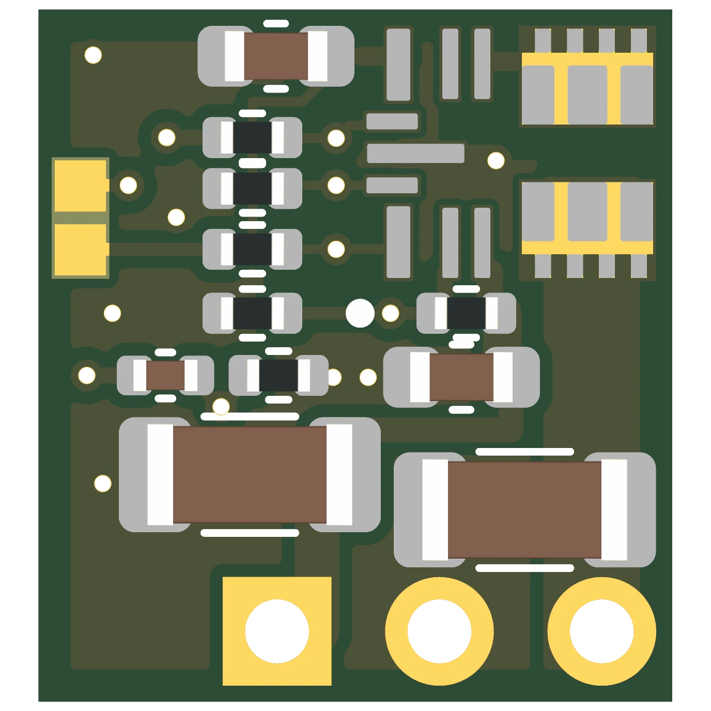
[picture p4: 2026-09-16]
docs/2026-09-13-mode-jumper-top.webp

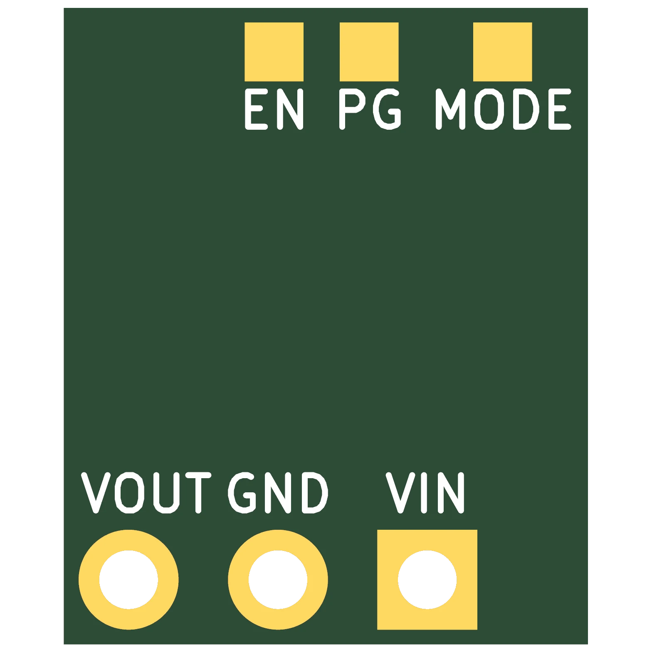
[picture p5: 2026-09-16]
docs/2026-09-13-floorplan-compact-bottom.webp

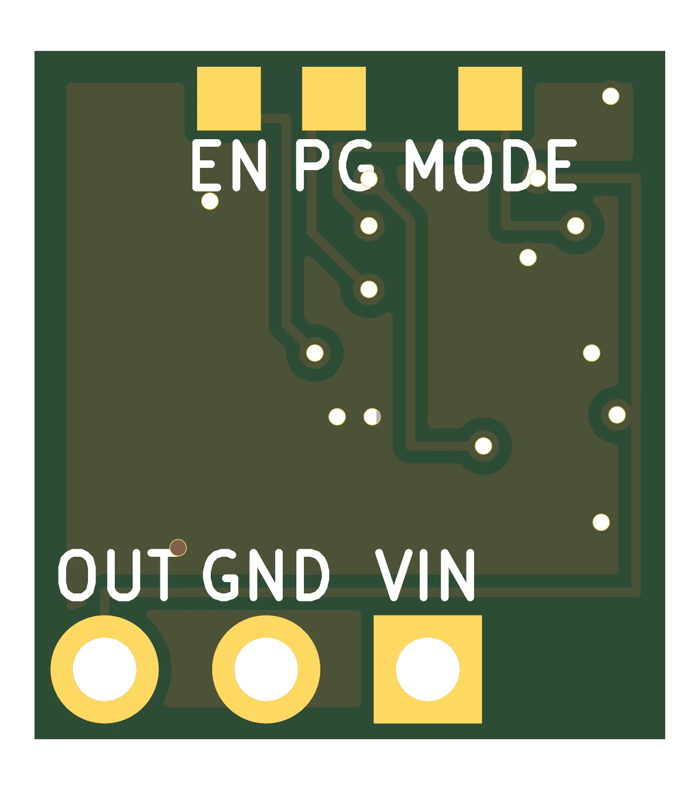
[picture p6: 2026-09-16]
docs/2026-09-13-routed-bottom.webp

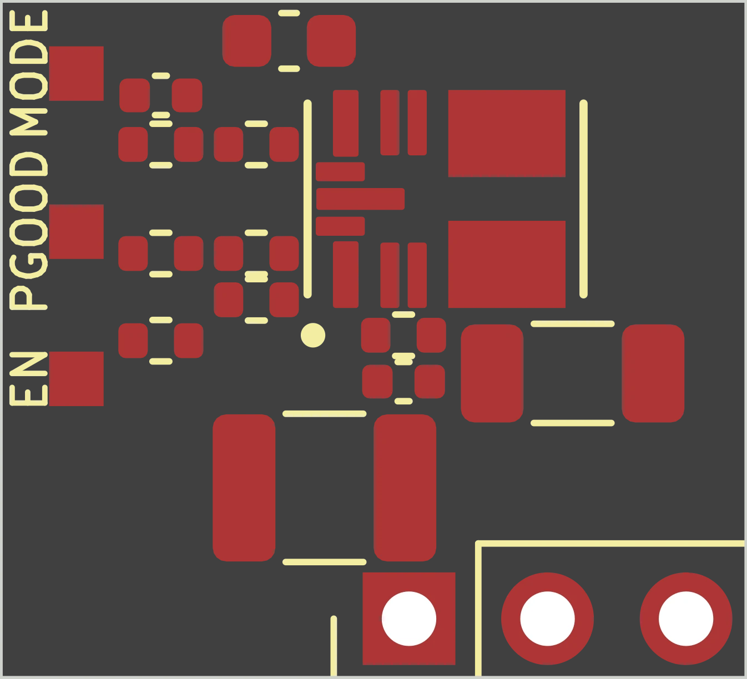
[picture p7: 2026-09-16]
docs/2026-09-13-floorplan-single-header.webp

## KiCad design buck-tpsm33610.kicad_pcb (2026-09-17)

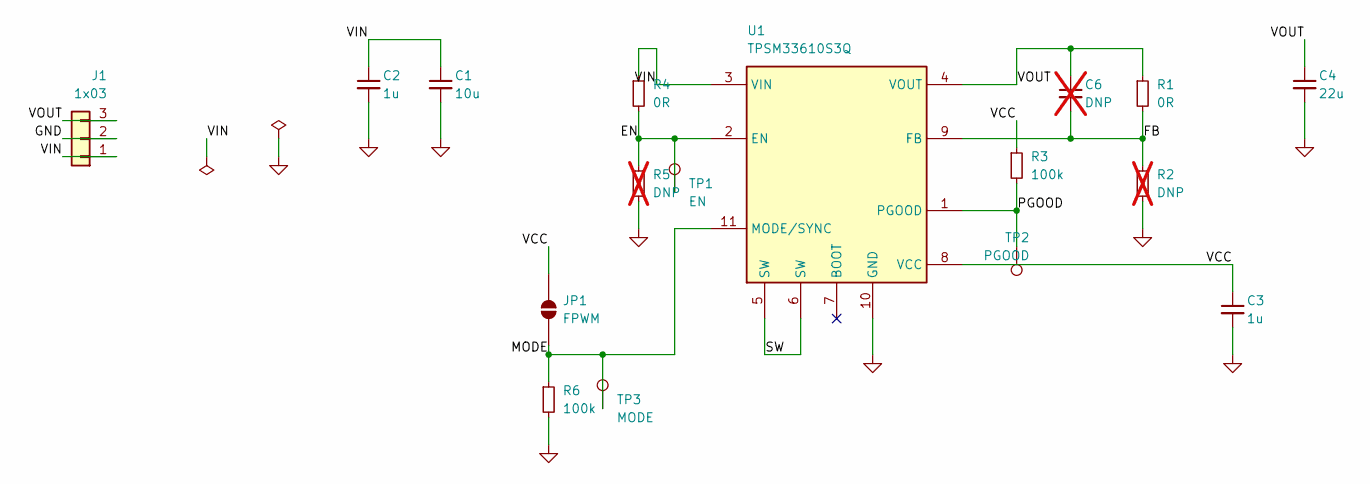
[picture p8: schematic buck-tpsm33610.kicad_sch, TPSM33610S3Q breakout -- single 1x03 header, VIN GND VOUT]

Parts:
C1: 10u; C_1206_3216Metric; MPN CGA5L1X7R1H106K160AC
C2, C3: 1u; C_0603_1608Metric; MPN CL10B105KB8NQNC
C4: 22u; C_1206_3216Metric; MPN EMK316BB7226ML-T
C6: DNP; C_0402_1005Metric; not fitted
J1: 1x03; PinHeader_1x03_P2.54mm_Vertical_NoSilk; MPN 61300311121
JP1: FPWM; SolderJumper_2_P1.00mm_Open_Pad0.8x0.4mm
R1, R4: 0R; R_0402_1005Metric; MPN RC0402JR-070RL
R2, R5: DNP; R_0402_1005Metric; not fitted
R3, R6: 100k; R_0402_1005Metric; MPN RC0402FR-07100KL
TP1: EN; TestPad_1.0x1.0mm
TP2: PGOOD; TestPad_1.0x1.0mm
TP3: MODE; TestPad_1.0x1.0mm
U1: TPSM33610S3Q; TPSM336xx_QFN-FCMOD-11_RDN0011B_TI; MPN TPSM33610S3QRDNRQ1

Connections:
/EN: R4.2, R5.1, TP1.1, U1.2 (EN)
/FB: C6.2, R1.2, R2.1, U1.9 (FB)
/MODE: JP1.2 (B), R6.1, TP3.1, U1.11 (MODE/SYNC)
/PGOOD: R3.2, TP2.1, U1.1 (PGOOD)
/SW: U1.5 (SW), U1.6 (SW)
/VCC: C3.1, JP1.1 (A), R3.1, U1.8 (VCC)
/VIN: C1.1, C2.1, J1.1, R4.1, U1.3 (VIN)
/VOUT: C4.1, C6.1, J1.3, R1.1, U1.4 (VOUT)
GND: C1.2, C2.2, C3.2, C4.2, J1.2, R2.2, R5.2, R6.2, U1.10 (GND)

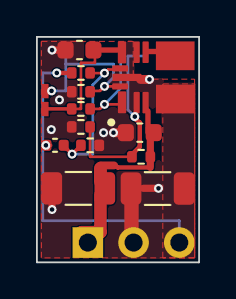
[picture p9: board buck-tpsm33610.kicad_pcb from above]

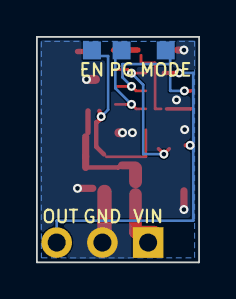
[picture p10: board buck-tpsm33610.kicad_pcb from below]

Board: 2 copper layers, 9.0 x 12.5 mm, 17 parts (3 on the bottom side), 9 nets.

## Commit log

2026-09-16 buck-tpsm33610: new 3-36 V to 3.3 V 1 A breakout, generated end to end
    TI TPSM33610S3QRDNRQ1 on 2 layers, 9.01 x 12.525 mm (112.9 mm^2), one
    1x03 header (VIN GND VOUT) with EN/PGOOD/MODE solder pads on the back
    and JP1, a solder jumper that selects FPWM by tying MODE to VCC.
    Everything is generated and the scripts are the source of truth:
    variants.py holds the geometry, gen_sym/gen_fp/gen_sch/gen_pcb build the
    symbol, footprints, schematic and board, project_settings.py owns the
    .kicad_pro because pcbnew's save rewrites it from KiCad defaults.
    Verified at this commit:
    ERC 0 errors, 0 warnings
    netlist 9 nets, 40 nodes, 17 components, matches intent
    DRC 0 errors,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
    [buck-tpsm33610.kicad_pcb, buck-tpsm33610.kicad_sch]
2026-09-16 buck-tpsm33610: rotate C1, swap R4/C2, and fix the resistance measurement basis
    C1 turns 180 so its VIN pad faces U1 instead of away from it. The VIN run now
    stops at the east pad, 2.95 mm short of where it used to, and never crosses
    under the body; the C1 -> J1.1 leg climbs the east side; C1's GND stub and its
    via move to the west pad. C2 and R4 swap so the input cap, not a 0R EN pull-up
    carrying ~10 nA, sits hard against U1's pin row (SNVSCS7E 8.5.1 item 1).
    The 0.72 mm VIN vertical starts at y 5.050, not 4.889: at that width the round
    end cap reaches 0.36 mm below the start point and /EN's top edge is at 4.485,
    which left 0.044 mm against a 0.15 mm rule. 5.050 puts the cap 0.205 mm clear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
    [buck-tpsm33610.kicad_pcb]
2026-09-16 buck-tpsm33610: 3-36 V to 3.3 V 1 A break-out for the TI TPSM33610S3Q module
    Fully generated: the symbol, footprints, schematic and PCB are all outputs of
    the Python here, and the KiCad files are build artefacts.
    9.01 x 12.525 mm, 2 layers, 70 um ENIG, drawn to 200/200 so the copper weight
    stays reversible until checkout. DRC clean: 0 errors, 0 unconnected pads, two
    dispositioned warnings.
    UNBUILT -- never fabricated, assembled or powered. Thermal is an estimate
    (~105 C/W, not measured) and the 3.67 nH input loop is FastHenry-extracted
    board copper only, a lower bound that excludes the module's unpublished
    pad-to-die path.
    Squashed snapshot out of a private monorepo; per-change history is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
    [buck-tpsm33610.kicad_pcb, buck-tpsm33610.kicad_sch]
2026-09-16 README: correct the copper weight, the header, and the neck rating
    An independent review caught that the README described the PLAN, not the
    artefacts. Corrected against variants.py and the board file:
    - Copper is 35 um (1 oz), not 70 um. variants.py PROCESS["copper_um"] = 35.
    - Drawn to 150/150 um, not 200/200. variants.py track_mm/clearance_mm = 0.15,
    and .kicad_pro min_track_width = 0.15.
    - One 1x03 header (VIN GND VOUT), not two rows on 0.4 in. There is exactly one
    PinHeader_1x03 on the board and variants.py describes it as "single 1x03
    header". The board is 9.01 mm wide, so it cannot straddle a breadboard on
    0.4 in rows -- that claim was impossible on its face.
    Consequences, al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
2026-09-17 buck-tpsm33610: the board is drawn to 150/150, not 200/200 -- and that pins ENIG
    variants.py and two comments in gen_fp.py claimed the board is drawn to
    200 um track / 200 um clearance outside the module land. It is not: 35 copper
    tracks sit at 0.15 mm, and variants.py's own PROCESS has track_mm and
    clearance_mm at 0.15. Measured from the board, by width:
    0.15 x35 0.20 x4 0.245 x2 0.25 x7 0.30 x3 0.40 x5
    0.44 x1 0.50 x2 0.70 x3 0.72 x1 0.80 x1
    The claim was load-bearing, not decorative. The plan's argument for 200/200 was
    that it costs nothing and keeps the board orderable at 35 um HASL, 35 um ENIG
    and 70 um ENIG with no geometry change, so the copper weight stays reversible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
    [buck-tpsm33610.kicad_pcb]
2026-09-17 buck-tpsm33610: make four guards real, and write the DESIGN.md they defer to
    From an independent review of the board. None of these changed the built board;
    all four were gates that did not gate.
    1. check_net_ceilings() -- the abs-max audit was a proxy.
    check_abs_max() compares a U1 pin's rating against NET_VMAX[net_name], a
    hand-declared table keyed on the net's NAME. It never asked what else was on the
    net. Move R3's pull-up from VCC to VIN and pin 1 is still on a net called PGOOD,
    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
    [buck-tpsm33610.kicad_pcb]
2026-09-17 buck-tpsm33610: do not track KiCad editor lock files
    They appear while pcbnew or eeschema has the project open and were swept into
    the previous commit.
2026-09-17 buck-tpsm33610: what the input loop measures, against TI's own reference -- and the fabbed board is not repo HEAD
    Analysis only; the board is unbuilt and nothing here is a bench measurement. It
    records the extracted input loop, the vendors' own capacitor data, and the three
    things TI's datasheet and EVM do differently.
    The limit is not a ripple spec: SNVSCS7E 6.1 rates VIN to GND at 40 V abs max
    against a 36 V recommended maximum, and 7.3.1 warns that ringing above it damages
    the IC. At 36 V that leaves 4.0 V for everything.
    Against that, the C1/C2 anti-resonance spends ~5% and the switch edge spends the
    rest: the pin overshoot is L_trunk*Iout/t_edge, and TI publishes no edge rate, so
    it s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
2026-09-18 buck-tpsm33610: the board exists now, so §5 says what to do with it
    0b1d077 landed the analysis while §5 still read like a pre-fab checklist --
    its last item even said "the board is unbuilt", contradicting §4.4 two
    screens above.
    Splits §5 into this board (run 12-35 V; measure the edge before going
    higher; the backside 100 nF is retrofittable on 2 layers) and the next
    revision (stackup first; re-extract from the commit that is actually
    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
2026-09-18 buck-tpsm33610: do not redistribute TI's datasheet from this repo
    Split out of the dev-root monorepo, which is private and carried
    datasheets/TI-TPSM336xx-Q1-SNVSCS7E-revE.pdf (3.2 MB, SNVSCS7E Rev E) as a
    tracked file. This repository is public, so the PDF is removed from the whole
    history and datasheets/*.pdf is ignored.
    PROVENANCE.md already records the exact URL, the revision and the SHA-256, so
    the document stays re-fetchable and any claim sourced from it stays checkable.
    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
